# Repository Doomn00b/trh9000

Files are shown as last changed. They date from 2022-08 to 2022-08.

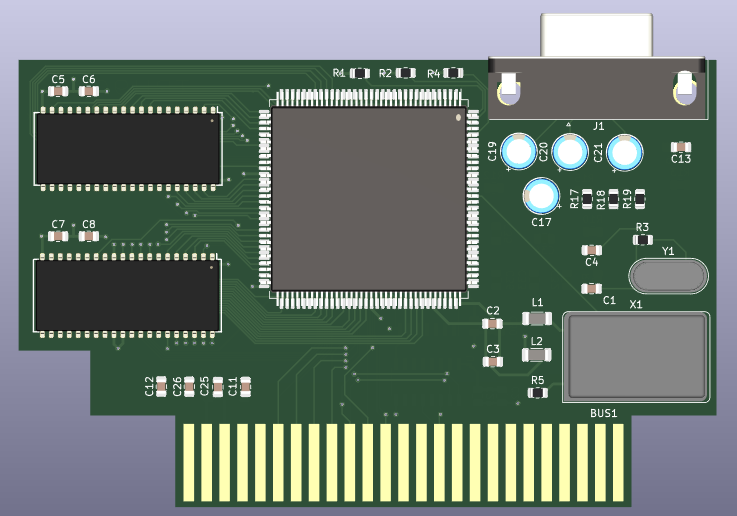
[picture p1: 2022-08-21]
Images/2022-08-20_22-34.png

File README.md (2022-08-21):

# TRH9000
The Yamaha V9990 based open-source video card for the MSX

## Introduction

If you ever spent just a few minutes on YouTube searching for MSX content, I bet you certainly found some footage covering the V9990. Well, not specifically the V9990 chip, but video cards based on it.

The first video card based on the unreleased, kind of obscure Yamaha V9990 VDP chip was the Graphics9000 (or GFX9000). The GFX9000 is (was) an MSX standard graphics expansion device for home computers developed by Sunrise in 1994.

It was designed as an expansion cartridge for the MSX standard that can be installed in a slot on a computer that also connects to the computer’s video output and monitor. The device works as an additional independent video controller.

The device is based on the Yamaha V9990 video controller (VDP). The chip was based on the never-produced V9978 chip, designed specifically for use in computers of the alleged but not implemented (by the time of this writing) MSX3 standard. Compared to the V9978, the V9990 is not backward compatible with the V99x8 chips, and thus cannot be used as the main video controller of standard MSX-compatible computers.

## The TRH9000

TRH9000 is the name of a brand new open-source implementation of the GFX9000. It is a community effort to create everything required to build MSX cartridges capable to run V9990 software.

The goal is to make the card more accessible and improve the amount of software available for it. 

There are a few folks activelly helping with the project and I would like to call them out here:

* Alexandre Souza
* Darlei Duarte
* lintweaker
* Luciano Sturaro
* Thiago Valença

## Development Log 

* 8/10/2022 - Routing day 1. Decided to move from TSOP-II-40 to SOJ-40 as the pins in the first encapsulation are more difficult to connect/route to the V9990. Using 0.21 tracks to optimize routing. Will provide the RGB connector (standard) and a pin header with the SVGA signal. Updating the forums and rest of stakeholders. First image status uploaded. 
* 8/8/2022 - Initial component placement on the PCB. Still lot of work to do in order to improve routing. 
* 8/4/2022 - Reviewed the footprints in preparation to start creating the first PCB draft. Had to create a custom TSOP-2-40 footprint as I could't find any on the net. Using 0805 for the resistors and ceramic capacitors. THT electrolytics. Reviewing the list of pending questions to get everything ready for the PCB creation. (REV0)
* 8/2/2022 - I just finished the first (rev0) draft of the schematics and I'll run it through more experienced MSX hardware developers. Please, if you feel you have something to add, clone the repo and contribute. You can also reach out if you want to suggest something. You can see a PDF with the first draft [here](Docs/TRH9000_Schema_Revision_0.pdf). Kicad files are stored on the [hardware/kicad](hardware/Kicad/) folder. (REV0)
* 8/15/2022 - Merged changes proposed by Doomn00b. 
* 8/20/2022 - Routing. Almost finished routing for the VDP. Moved back the footprint for the 14mhz oscillator to THT as it is easier to find outside US/Europe and I have a bunch laying around here. Organized all components into the PCB. Removed the holed in the cartridge so I can better measure them in the standard MSX cartridge. Changed the RGB connector footprint to a shorter version so we can fit it in the standard size cartridge. Fixed multiple footprints to 0805 as we will be standardizing in that size.

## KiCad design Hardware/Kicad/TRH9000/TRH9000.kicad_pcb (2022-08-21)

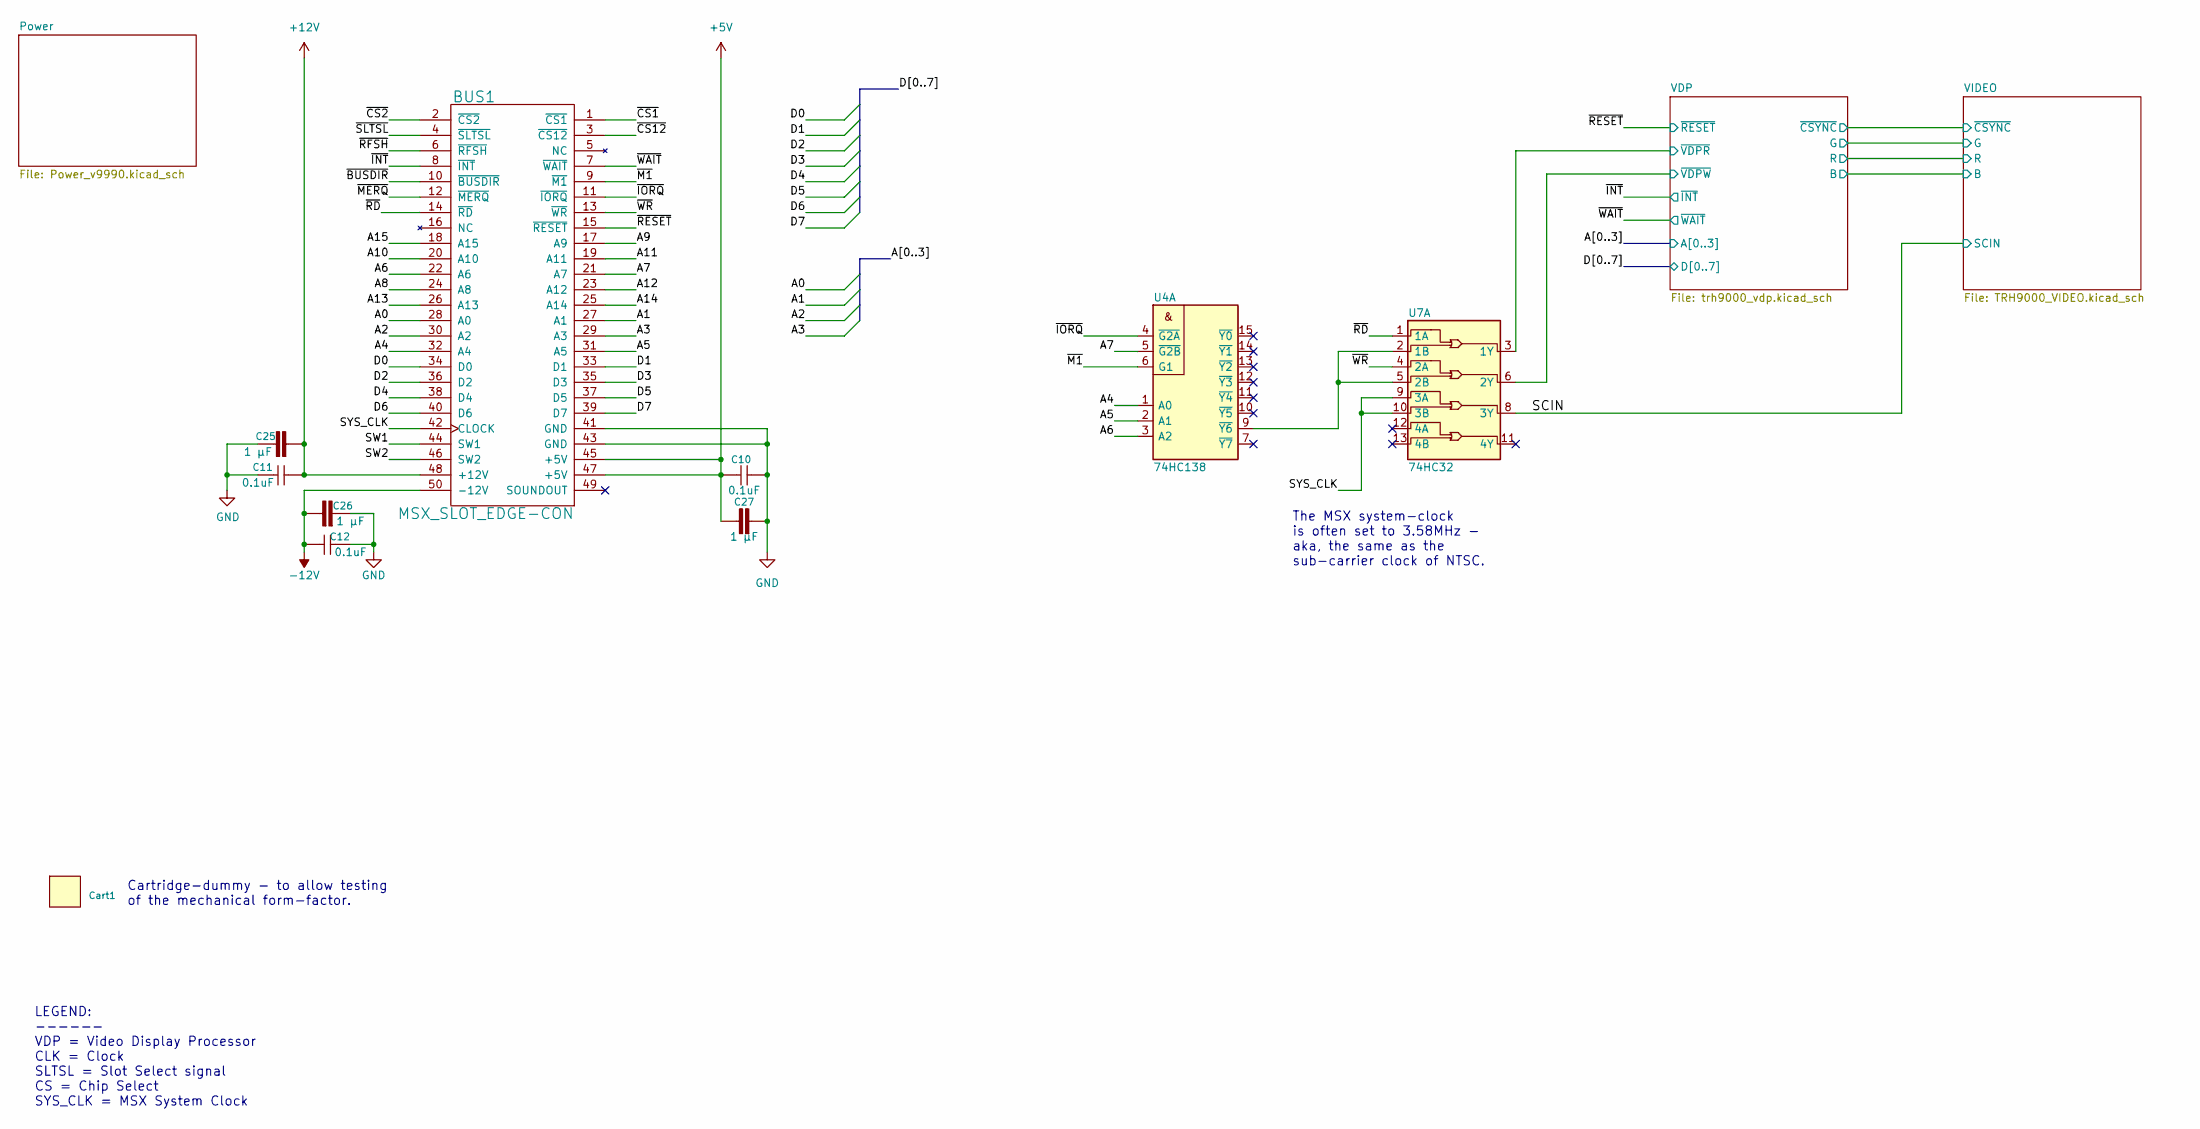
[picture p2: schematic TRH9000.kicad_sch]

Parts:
BUS1: MSX_SLOT_EDGE-CON; msx_cartridge; MPN n/a
C10: 0.1uF; C_0805_2012Metric; Voltage rating 50V
C11, C12: 0.1uF; C_0805_2012Metric; Voltage rating 50V; MPN CC0805JPX7R9BB104
C25, C26, C27: 1 µF; C_0805_2012Metric; Voltage rating 50V; MPN CL21B105KBFNNNF
Cart1: MSX-cartridge_dummy; MSX-cart-dummy; MPN n/a
U4: 74HC138; SO-16_3.9x9.9mm_P1.27mm; MPN 74HC138
U7: 74HC32; SO-14_3.9x8.65mm_P1.27mm; MPN 74HC32

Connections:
+5V: BUS1.45 (+5V), BUS1.47 (+5V), C10.1, C27.1; also elsewhere on the board
+12V: BUS1.48 (+12V), C11.2, C25.2; also elsewhere on the board
-12V: BUS1.50 (-12V), C12.1, C26.1
/A0: BUS1.28 (A0); also elsewhere on the board
/A1: BUS1.27 (A1); also elsewhere on the board
/A2: BUS1.30 (A2); also elsewhere on the board
/A3: BUS1.29 (A3); also elsewhere on the board
/A4: BUS1.32 (A4), U4.1 (A0)
/A5: BUS1.31 (A5), U4.2 (A1)
/A6: BUS1.22 (A6), U4.3 (A2)
/A7: BUS1.21 (A7), U4.5 (~G2B)
/A8: BUS1.24 (A8)
/A9: BUS1.17 (A9)
/A10: BUS1.20 (A10)
/A11: BUS1.19 (A11)
/A12: BUS1.23 (A12)
/A13: BUS1.26 (A13)
/A14: BUS1.25 (A14)
/A15: BUS1.18 (A15)
/D0: BUS1.34 (D0); also elsewhere on the board
/D1: BUS1.33 (D1); also elsewhere on the board
/D2: BUS1.36 (D2~); also elsewhere on the board
/D3: BUS1.35 (D3); also elsewhere on the board
/D4: BUS1.38 (D4); also elsewhere on the board
/D5: BUS1.37 (D5); also elsewhere on the board
/D6: BUS1.40 (D6); also elsewhere on the board
/D7: BUS1.39 (D7); also elsewhere on the board
/SCIN: U7.8 (3Y)
/SW1: BUS1.44 (SW1)
/SW2: BUS1.46 (SW2)
/SYS_CLK: BUS1.42 (CLOCK), U7.9 (3A), U7.10 (3B)
/VDP/~VDPR: U7.3 (1Y); also elsewhere on the board
/VDP/~VDPW: U7.6 (2Y); also elsewhere on the board
/~BUSDIR: BUS1.10 (~BUSDIR)
/~CS1: BUS1.1 (~CS1)
/~CS2: BUS1.2 (~CS2)
/~CS12: BUS1.3 (~CS12)
/~INT: BUS1.8 (~INT); also elsewhere on the board
/~IORQ: BUS1.11 (~IORQ), U4.4 (~G2A)
/~M1: BUS1.9 (~M1), U4.6 (G1)
/~MERQ: BUS1.12 (~MERQ)
/~RD: BUS1.14 (~RD), U7.1 (1A)
/~RESET: BUS1.15 (~RESET); also elsewhere on the board
/~RFSH: BUS1.6 (~RFSH)
/~SLTSL: BUS1.4 (~SLTSL)
/~WAIT: BUS1.7 (~WAIT); also elsewhere on the board
/~WR: BUS1.13 (~WR), U7.4 (2A)
GND: BUS1.41 (GND), BUS1.43 (GND), C10.2, C11.1, C12.2, C25.1, C26.2, C27.2; also elsewhere on the board
unnamed: U4.9 (~Y6), U7.2 (1B), U7.5 (2B)

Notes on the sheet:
The MSX system-clock is often set to 3.58MHz - aka, the same as the sub-carrier clock of NTSC.
Cartridge-dummy - to allow testing of the mechanical form-factor.
LEGEND: ------ VDP = Video Display Processor CLK = Clock SLTSL = Slot Select signal CS = Chip Select SYS_CLK = MSX System Clock

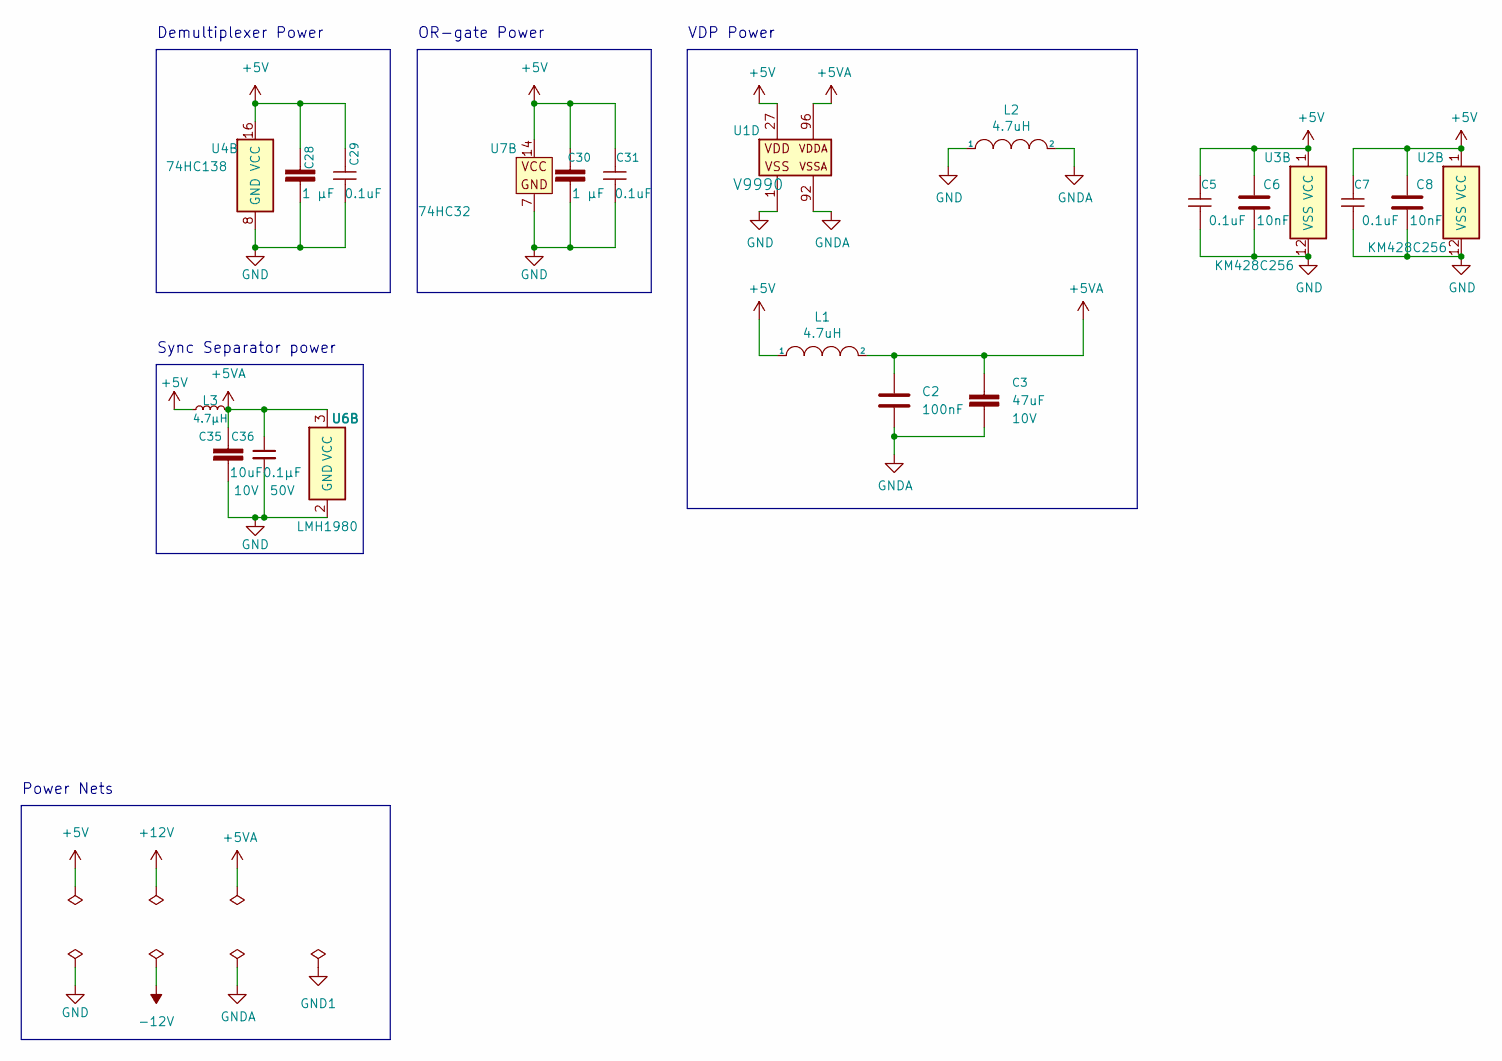
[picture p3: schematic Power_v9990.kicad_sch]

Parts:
C2: 100nF; C_0805_2012Metric
C3: 47uF; C_0805_2012Metric; Voltage rating 10V; Tolerance ±20%; MPN GRM21BR61A476ME15K
C5, C7: 0.1uF; C_0805_2012Metric; Voltage rating 50V; MPN CC0805JPX7R9BB104
C6, C8: 10nF; C_0805_2012Metric
C28, C30: 1 µF; C_0805_2012Metric; Voltage rating 50V; MPN CL21B105KBFNNNF
C29: 0.1uF; C_0805_2012Metric
C31: 0.1uF; C_0805_2012Metric; Voltage rating 50V
C35: 10uF; C_0805_2012Metric_Pad1.18x1.45mm_HandSolder; Voltage rating 10V; Tolerance ±10%; MPN GRM21BR71A106KA73K
C36: 0.1µF; C_0805_2012Metric; Tolerance ±10%; Voltage Rating 50V; MPN CL10B104KB8NNNL
L1, L2: 4.7uH; L_1206_3216Metric
L3: 4.7µH; L_0805_2012Metric; Current Rating 0.4A; MPN MLZ2012M4R7HT000
U1: V9990; LQFP-128_28x28mm_P0.8mm; MPN V9990
U2, U3: KM428C256; SOJ-40_400mil
U4: 74HC138; SO-16_3.9x9.9mm_P1.27mm; MPN 74HC138
U6: LMH1980; VSSOP-10_3x3mm_P0.5mm; MPN LMH1980MM/NOPBCT
U7: 74HC32; SO-14_3.9x8.65mm_P1.27mm; MPN 74HC32

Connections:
+5V: C5.1, C6.2, C7.1, C8.2, C28.1, C29.1, C30.1, C31.1, L1.1, L3.1, U1.27 (VDD), U1.53 (VDD), U1.81 (VDD), U1.97 (VDD), U1.123 (VDD), U2.1 (VCC), U2.20 (VCC), U3.1 (VCC), U3.20 (VCC), U4.16 (VCC), U7.14 (VCC); also elsewhere on the board
+5VA: C2.1, C3.1, C35.1, C36.1, L1.2, L3.2, U1.96 (VDDA), U6.3 (VCC)
/A0: U1.4 (MODE0); also elsewhere on the board
/A1: U1.5 (MODE1); also elsewhere on the board
/A2: U1.6 (MODE2); also elsewhere on the board
/A3: U1.7 (MODE3); also elsewhere on the board
/D0: U1.114 (CD0); also elsewhere on the board
/D1: U1.115 (CD1); also elsewhere on the board
/D2: U1.116 (CD2); also elsewhere on the board
/D3: U1.117 (CD3); also elsewhere on the board
/D4: U1.119 (CD4); also elsewhere on the board
/D5: U1.120 (CD5); also elsewhere on the board
/D6: U1.121 (CD6); also elsewhere on the board
/D7: U1.122 (CD7); also elsewhere on the board
/VDP/B: U1.95 (B/D1/CB1); also elsewhere on the board
/VDP/G: U1.94 (G/D2/CB2); also elsewhere on the board
/VDP/HRESET: U1.105 (~HRESET/CB4); also elsewhere on the board
/VDP/MCKIN: U1.113 (MCKIN); also elsewhere on the board
/VDP/R: U1.93 (R/D3/CB3); also elsewhere on the board
/VDP/V0A0: U1.26 (V0_A0/KA0), U3.25 (A0)
/VDP/V0A1: U1.25 (V0_A1/KA1), U3.24 (A1)
/VDP/V0A2: U1.24 (V0_A2/KA2), U3.23 (A2)
/VDP/V0A3: U1.23 (V0_A3/KA3), U3.22 (A3)
/VDP/V0A4: U1.22 (V0_A4/KA4), U3.19 (A4)
/VDP/V0A5: U1.21 (V0_A5/KA5), U3.18 (A5)
/VDP/V0A6: U1.20 (V0_A6/KA6), U3.17 (A6)
/VDP/V0A7: U1.19 (V0_A7/KA7), U3.16 (A7)
/VDP/V0A8: U1.18 (V0_A8/KA8), U3.15 (A8)
/VDP/V0D0: U1.36 (V0_D0/KD0), U3.8 (W0/DQ0)
/VDP/V0D1: U1.35 (V0_D1/KD1), U3.9 (W1/DQ1)
/VDP/V0D2: U1.34 (V0_D2/KD2), U3.10 (W2/DQ2)
/VDP/V0D3: U1.33 (V0_D3/KD3), U3.11 (W3/DQ3)
/VDP/V0D4: U1.31 (V0_D4/KD4), U3.31 (W4/DQ4)
/VDP/V0D5: U1.30 (V0_D5/KD5), U3.32 (W5/DQ5)
/VDP/V0D6: U1.29 (V0_D6/KD6), U3.33 (W6/DQ6)
/VDP/V0D7: U1.28 (V0_D7/KD7), U3.34 (W7/DQ7)
/VDP/V0S0: U1.52 (V0_S0), U3.3 (SDQ0)
/VDP/V0S1: U1.51 (V0_S1), U3.4 (SDQ1)
/VDP/V0S2: U1.50 (V0_S2), U3.5 (SDQ2)
/VDP/V0S3: U1.49 (V0_S3), U3.6 (SDQ3)
/VDP/V0S4: U1.48 (V0_S4), U3.36 (SDQ4)
/VDP/V0S5: U1.47 (V0_S5), U3.37 (SDQ5)
/VDP/V0S6: U1.46 (V0_S6), U3.38 (SDQ6)
/VDP/V0S7: U1.45 (V0_S7), U3.39 (SDQ7)
/VDP/V1A0: U1.80 (V1_A0), U2.25 (A0)
/VDP/V1A1: U1.79 (V1_A1), U2.24 (A1)
/VDP/V1A2: U1.78 (V1_A2), U2.23 (A2)
/VDP/V1A3: U1.77 (V1_A3), U2.22 (A3)
/VDP/V1A4: U1.76 (V1_A4), U2.19 (A4)
/VDP/V1A5: U1.74 (V1_A5), U2.18 (A5)
/VDP/V1A6: U1.73 (V1_A6), U2.17 (A6)
/VDP/V1A7: U1.72 (V1_A7), U2.16 (A7)
/VDP/V1A8: U1.71 (V1_A8), U2.15 (A8)
/VDP/V1D0: U1.82 (V1_D0), U2.8 (W0/DQ0)
/VDP/V1D1: U1.83 (V1_D1), U2.9 (W1/DQ1)
/VDP/V1D2: U1.84 (V1_D2), U2.10 (W2/DQ2)
/VDP/V1D3: U1.85 (V1_D3), U2.11 (W3/DQ3)
/VDP/V1D4: U1.87 (V1_D4), U2.31 (W4/DQ4)
/VDP/V1D5: U1.88 (V1_D5), U2.32 (W5/DQ5)
/VDP/V1D6: U1.89 (V1_D6), U2.33 (W6/DQ6)
/VDP/V1D7: U1.90 (V1_D7), U2.34 (W7/DQ7)
/VDP/V1S0: U1.61 (V1_S0), U2.3 (SDQ0)
/VDP/V1S1: U1.60 (V1_S1), U2.4 (SDQ1)
/VDP/V1S2: U1.59 (V1_S2), U2.5 (SDQ2)
/VDP/V1S3: U1.58 (V1_S3), U2.6 (SDQ3)
/VDP/V1S4: U1.57 (V1_S4), U2.36 (SDQ4)
/VDP/V1S5: U1.56 (V1_S5), U2.37 (SDQ5)
/VDP/V1S6: U1.55 (V1_S6), U2.38 (SDQ6)
/VDP/V1S7: U1.54 (V1_S7), U2.39 (SDQ7)
/VDP/VMREQ: U1.124 (~VMREQ); also elsewhere on the board
/VDP/VRESET: U1.106 (~VRESET/CB5); also elsewhere on the board
/VDP/X1: U1.98 (XTAL1); also elsewhere on the board
/VDP/X2: U1.99 (XTAL2); also elsewhere on the board
/VDP/~CSYNC: U1.102 (~CSYNC/FLM); also elsewhere on the board
/VDP/~V0_CAS: U1.39 (~V0_CAS), U3.27 (~CAS)
/VDP/~V0_RAS: U1.38 (~V0_RAS), U3.14 (~RAS)
/VDP/~V0_SC: U1.42 (~V0_SC), U3.2 (SC)
/VDP/~V0_TR: U1.41 (~V0_TR/OE), U3.7 (~DT/~OE)
/VDP/~V0_WE: U1.40 (~V0_WE), U3.13 (R~WB/~WE)
/VDP/~V1_CAS: U1.63 (~V1_CAS), U2.27 (~CAS)
/VDP/~V1_RAS: U1.62 (~V1_RAS), U2.14 (~RAS)
/VDP/~V1_SC: U1.67 (V1_SC), U2.2 (SC)
/VDP/~V1_SOE: U1.68 (~V1_SOE), U2.35 (~SE)
/VDP/~V1_TR: U1.66 (~V1_TR/OE), U2.7 (~DT/~OE)
/VDP/~V1_WE: U1.65 (~V1_WE), U2.13 (R~WB/~WE)
/VDP/~VDPR: U1.2 (~CSW); also elsewhere on the board
/VDP/~VDPW: U1.3 (~CSR); also elsewhere on the board
/VDP/~VO_SOE: U1.43 (~V0_SOE), U3.35 (~SE)
/~INT: U1.126 (~INT0), U1.127 (~INT1); also elsewhere on the board
/~RESET: U1.110 (~RESET); also elsewhere on the board
/~WAIT: U1.128 (~WAIT); also elsewhere on the board
GND: C5.2, C6.1, C7.2, C8.1, C28.2, C29.2, C30.2, C31.2, C35.2, C36.2, L2.1, U1.1 (VSS), U1.17 (VSS), U1.32 (VSS), U1.44 (VSS), U1.64 (VSS), U1.75 (VSS), U1.86 (VSS), U1.100 (VSS), U1.107 (VSS), U1.118 (VSS), U2.12 (VSS), U2.21 (VSS), U2.29 (DSF), U2.30 (VSS), U2.40 (VSS), U3.12 (VSS), U3.21 (VSS), U3.29 (DSF), U3.30 (VSS), U3.40 (VSS), U4.8 (GND), U6.2 (GND), U7.7 (GND); also elsewhere on the board
GNDA: C2.2, C3.2, L2.2, U1.92 (VSSA); also elsewhere on the board

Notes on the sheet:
OR-gate Power
Sync Separator power
Power Nets
Demultiplexer Power
VDP Power

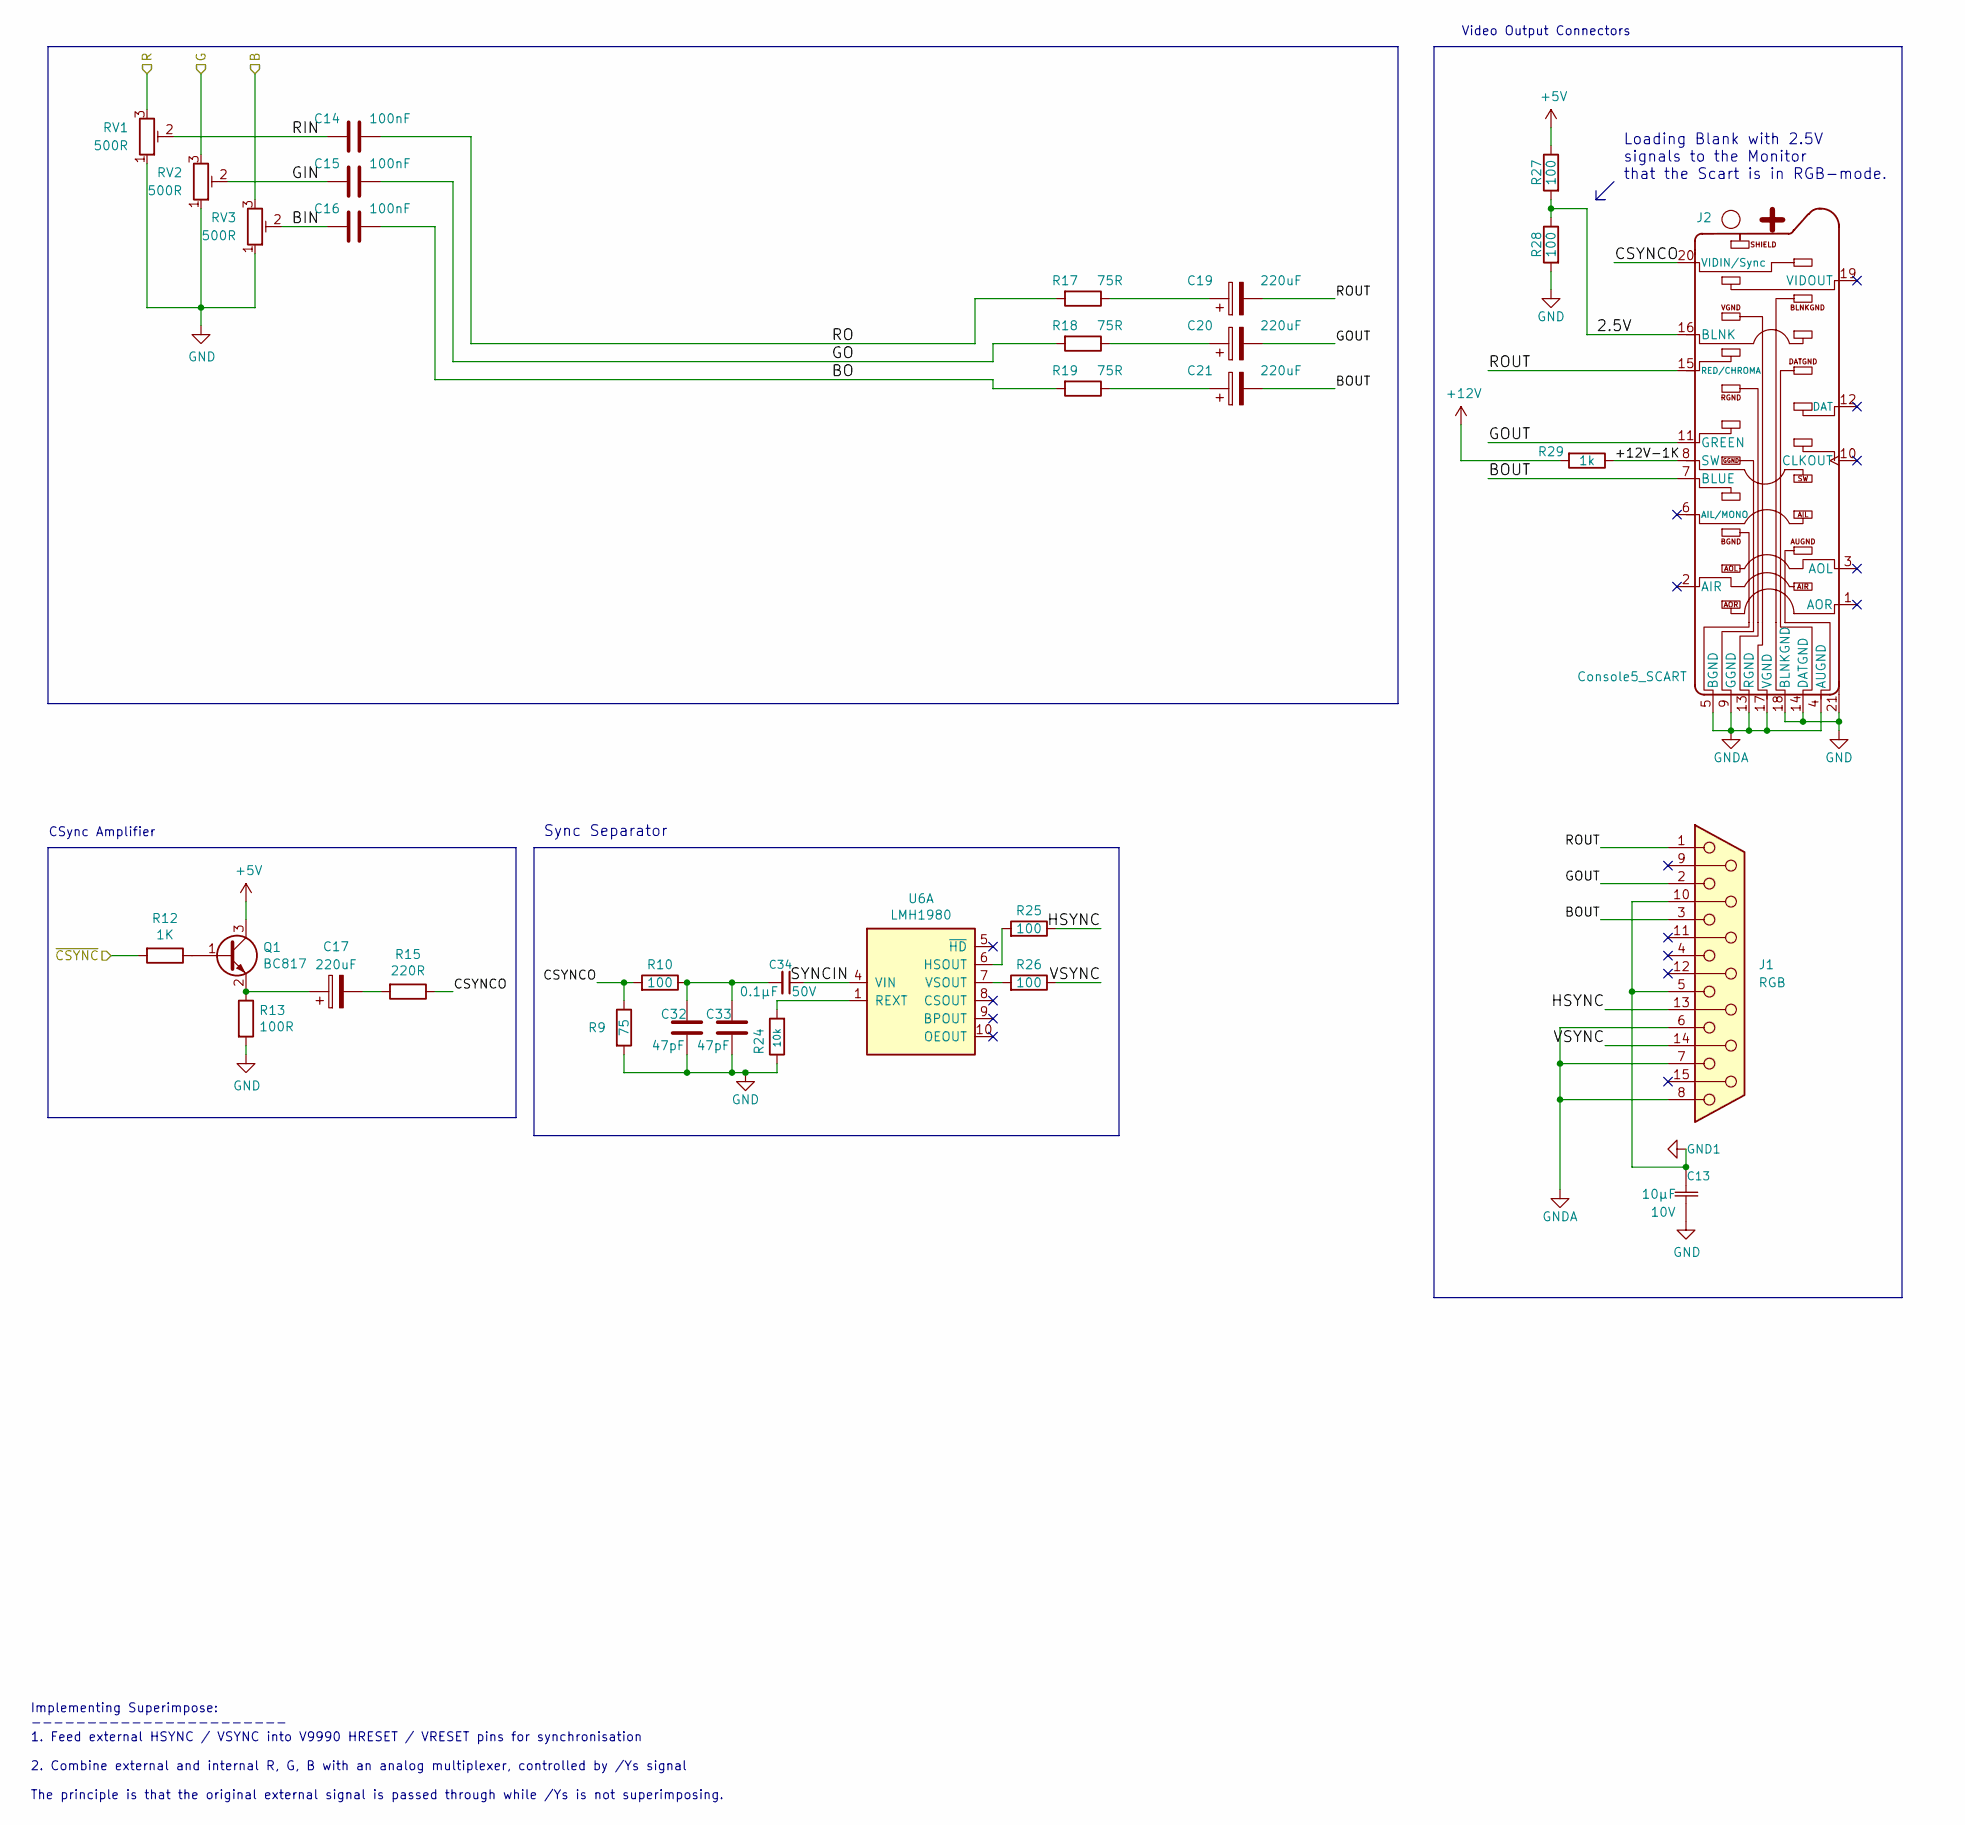
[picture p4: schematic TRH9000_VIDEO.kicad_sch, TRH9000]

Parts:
C13: 10µF; C_0805_2012Metric; Voltage rating 10V; MPN GRM188D71A106KA73D
C14, C15, C16: 100nF; C_0805_2012Metric
C17, C19, C20, C21: 220uF; CP_Radial_D5.0mm_P2.50mm
C32, C33: 47pF; C_0805_2012Metric
C34: 0.1µF; C_0805_2012Metric; Tolerance ±10%; Voltage Rating 50V; MPN CL10B104KB8NNNL
J1: RGB; DSUB-15-HD_Female_Horizontal_P2.29x1.98mm_EdgePinOffset3.03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
J2: Console5_SCART; SCART-21_Female_Horizontal_P1.905x2.54mm_EdgePinOffset10.7mm; MPN N/A
Q1: BC817; SOT-23
R9: 75; R_0805_2012Metric
R10, R25, R26: 100; R_0805_2012Metric
R12: 1K; R_0805_2012Metric
R13: 100R; R_0805_2012Metric
R15: 220R; R_0805_2012Metric
R17, R18, R19: 75R; R_0805_2012Metric
R24: 10k; C_0805_2012Metric; MPN RC0603FR-0710KL
R27, R28: 100; R_0603_1608Metric
R29: 1k; R_0603_1608Metric
RV1, RV2, RV3: 500R; Potentiometer_Bourns_3314G_Vertical
U6: LMH1980; VSSOP-10_3x3mm_P0.5mm; MPN LMH1980MM/NOPBCT

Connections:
+5V: Q1.3 (C), R27.1; also elsewhere on the board
+12V: R29.2; also elsewhere on the board
/VDP/B: RV3.3; also elsewhere on the board
/VDP/G: RV2.3; also elsewhere on the board
/VDP/R: RV1.3; also elsewhere on the board
/VDP/~CSYNC: R12.2; also elsewhere on the board
/VIDEO/2.5V: J2.16 (BLNK), R27.2, R28.1
/VIDEO/+12V-1K: J2.8 (SW), R29.1
/VIDEO/BIN: C16.2, RV3.2
/VIDEO/BO: C16.1, R19.2
/VIDEO/BOUT: C21.2, J1.3, J2.7 (BLUE)
/VIDEO/CSYNCO: J2.20 (VIDIN/Sync), R9.1, R10.2, R15.1
/VIDEO/GIN: C15.2, RV2.2
/VIDEO/GO: C15.1, R18.2
/VIDEO/GOUT: C20.2, J1.2, J2.11 (GREEN)
/VIDEO/HSYNC: J1.13, R25.1
/VIDEO/RIN: C14.2, RV1.2
/VIDEO/RO: C14.1, R17.2
/VIDEO/ROUT: C19.2, J1.1, J2.15 (RED/CHROMA)
/VIDEO/SYNCIN: C34.1, U6.4 (VIN)
/VIDEO/VSYNC: J1.14, R26.1
GND: C13.1, C32.2, C33.2, J2.14 (DATGND), J2.18 (BLNKGND), J2.21 (SH), R9.2, R13.2, R24.1, R28.2, RV1.1, RV2.1, RV3.1; also elsewhere on the board
GND1: C13.2, J1.5, J1.10
GNDA: J1.6, J1.7, J1.8, J2.4 (AUGND), J2.5 (BGND), J2.9 (GGND), J2.13 (RGND), J2.17 (VGND); also elsewhere on the board
unnamed: C17.1, Q1.2 (E), R13.1
unnamed: C17.2, R15.2
unnamed: C19.1, R17.1
unnamed: C20.1, R18.1
unnamed: C21.1, R19.1
unnamed: C32.1, C33.1, C34.2, R10.1
unnamed: Q1.1 (B), R12.1
unnamed: R24.2, U6.1 (REXT)
unnamed: R25.2, U6.6 (HSOUT)
unnamed: R26.2, U6.7 (VSOUT)

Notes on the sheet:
Sync Separator
CSync Amplifier
Loading Blank with 2.5V signals to the Monitor that the Scart is in RGB-mode.
Video Output Connectors
Implementing Superimpose: ----------------------- 1. Feed external HSYNC / VSYNC into V9990 HRESET / VRESET pins for synchronisation 2. Combine external and internal R, G, B with an analog multiplexer, controlled by /Ys signal The principle is that the original external signal is passed through whi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

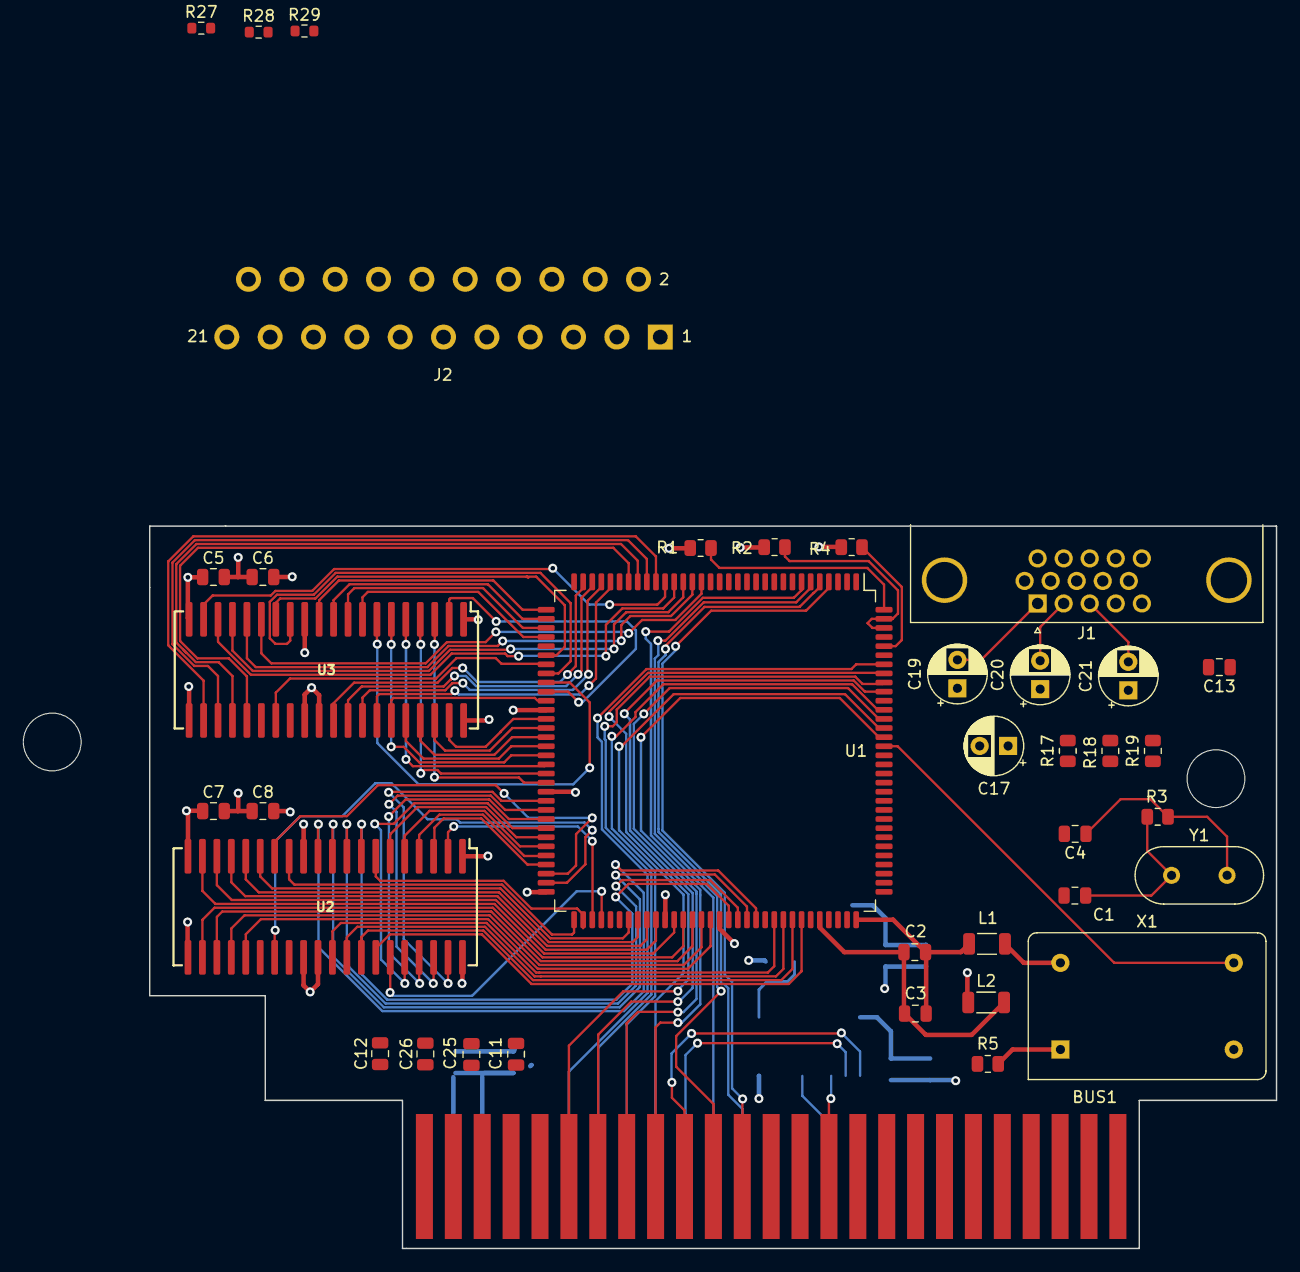
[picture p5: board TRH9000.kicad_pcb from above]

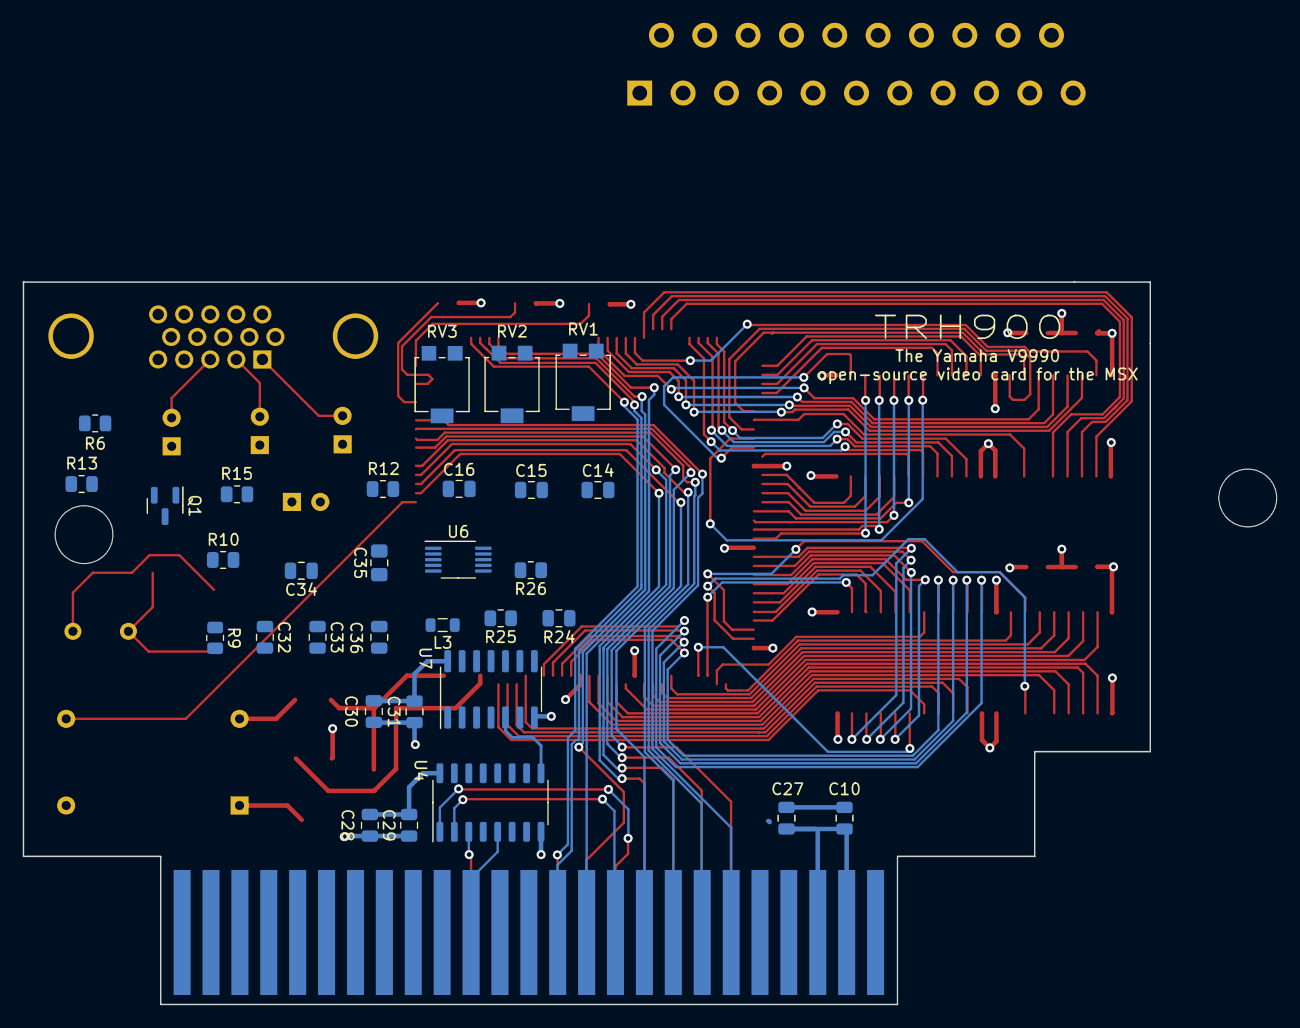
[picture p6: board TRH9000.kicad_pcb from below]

Board: 4 copper layers, 99.1 x 63.5 mm, 70 parts (31 on the bottom side), 131 nets.

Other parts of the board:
C1, C4: 27pF; C_0805_2012Metric
R1, R2, R4, R5, R6: 4K7; R_0805_2012Metric
R3: 10M; R_0805_2012Metric
X1: 14.31818MHz; Oscillator_DIP-14
Y1: 21.47727Mhz; Crystal_HC49-U_Vertical

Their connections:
+5V: R1.1, R2.1, R4.1, R5.1, R6.2, X1.1 (Vcontrol), X1.14 (Vcc); also elsewhere on the board
/VDP/HRESET: R5.2; also elsewhere on the board
/VDP/MCKIN: X1.8 (OUT); also elsewhere on the board
/VDP/VMREQ: R4.2; also elsewhere on the board
/VDP/VRESET: R6.1; also elsewhere on the board
/VDP/X1: C1.1, R3.2, Y1.1; also elsewhere on the board
/VDP/X2: C4.1, R3.1, Y1.2; also elsewhere on the board
/~INT: R2.2; also elsewhere on the board
/~WAIT: R1.2; also elsewhere on the board
GND: C1.2, C4.2, X1.7 (GND); also elsewhere on the board

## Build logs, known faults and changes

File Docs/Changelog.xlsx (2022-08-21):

Date | Note | Contributor
2022-08-05 | Added a changelog-file, altered the .gitignore according to the Kicad standard, started adding annotations to the datasheets for navigation. | Doomn00b
2022-08-11 | Changed the project to use generic links instead of local links, merged footprint libraries into one, merged symbol libraries into one, started rewriting V9990 datasheet with Open Sans font, for future open source datasheet | Doomn00b
 | Changed V9990 symbol and footprint
 | Replaced C3 THT capacitor with SMD.
2022-08-12 | Replaced RGB-connector with real VGA conn from Amphenol, changed decoupling, put power-parts on their own sheet,
 | Replaced big 14MHz oscillator with SMD one,
 | Changed the glue logic to use Advanced 74xx versions, with far higher performance.
 | Removed Composite video and replaced with RGB Scart
2022-08-20 | Routing. Almost finished routing for the VDP. Moved back the footprint for the 14mhz oscillator to THT as it is easier to find outside US/Europe and I have a bunch laying around here. Organized all components into the PCB. Removed the holed in the cartridge so I can better measure them in the standard MSX cartridge. Changed the RGB connector footprint to a shorter version so we can fit it in the standard size cartridge. Fixed multiple footprints to 0805 as we will be standardizing in that size.

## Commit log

2022-08-20 Started routing the PCB, adding cut-outs to separate the analog from digital signal-domains.
    [Changelog.xlsx, Power_v9990.kicad_sch, TRH9000.kicad_pcb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]
2022-08-21 More adjustments of layout.
    [Changelog.xlsx]
2022-08-21 Merging in most recent upstream changes.
    [Changelog.xlsx, Power_v9990.kicad_sch, TRH9000.kicad_pcb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]

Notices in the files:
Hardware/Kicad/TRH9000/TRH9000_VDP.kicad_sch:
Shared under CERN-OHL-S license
